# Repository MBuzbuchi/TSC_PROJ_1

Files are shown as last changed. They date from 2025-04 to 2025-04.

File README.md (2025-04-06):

# TSC_PROJ_1

E_Book proj

# _**Bloc Scheme**_


# _**Description of Hardware Functionality**_

Below is an extended list of the hardware components identified in the schematic, along with each component’s role and functionality, 
plus some operational details. These explanations help clarify how the entire system is built and why these design choices were made.

## 1. USB-C Connector & ESD Protection

### Key Components
- **USBLC6-2SC6Y** – TVS (Transient Voltage Suppressor) diode specialized for USB data line protection.  
  - **Approx. Price**: \$0.10–\$0.30 (single unit)  
- **PFMF.050.1** – resettable fuse (PTC) protecting the power line from excessive current.  
  - **Approx. Price**: \$0.10–\$0.20  
- **R2-USB1 / R2-USB** (5 kΩ) – matching/termination resistors on the USB D+ and D– data lines.  
  - **Approx. Price**: \$0.01–\$0.02 each  

### Function
- The USB-C connector supplies both power (5 V) to the system and USB data connectivity.  
- The ESD protection diode safeguards the USB data lines from electrostatic discharges up to several kV, maintaining the integrity of the data signals and internal converters.  
- The PTC fuse automatically resets once the current drops, preventing damage when short circuits or overcurrent situations occur on the USB port.

### Operational Data
- 5 V power supply from the USB, typically up to 500 mA (USB 2.0), or more depending on the USB-C source.  
- Data transfer rates up to 480 Mbps (USB 2.0 High Speed).

---

## 2. Voltage Regulators (LDO Voltage Regulator)

### Key Components
- **XC6220A331MR-G** – an LDO (Low Dropout) regulator delivering a stable 3.3 V output.  
  - **Approx. Price**: \$0.20–\$0.50  
- **DMG2305UX-7** – P-channel MOSFET used for power switching (possibly for reverse voltage protection or for reducing quiescent current when switching between USB and battery power).  
  - **Approx. Price**: \$0.10–\$0.30  

### Function
- Provides a constant 3.3 V rail for powering the ESP32-C6 and other logic circuits/sensors.  
- Can also serve as an additional protection stage, keeping the supply stable and filtering noise that may come from the USB source.

### Operational Data
- Input voltage range: ~3.5 V to 5.5 V (according to the LDO specs).  
- Output current up to ~300 mA.  
- Built-in overcurrent and thermal shutdown protection, ensuring circuit safety.

---

## 3. Li-Po Charging Controller (MCP73831/73832)

### Key Component
- **MCP73831** – a simple charge-management IC, configurable by an external resistor (PROG) to set the charge current.  
  - **Approx. Price**: \$0.50–\$0.80  

### Function
- Safely charges a single-cell Li-Po battery, regulating up to 4.2 V and controlling a maximum charge current.  
- Integrates temperature monitoring (via external NTC or dedicated resistor), charge status indicator (LED), and automatically switches to a float maintenance mode once the battery is fully charged.

### Operational Data
- Typically powered by a 5 V USB input.  
- Charge current (set by the PROG resistor) – e.g., 100 mA, 500 mA, etc., depending on the battery requirements.  
- Over-voltage, over-temperature, and short-circuit protection.

---

## 4. Single-Cell Li-Po Battery

### Function
- Stores electrical energy to power the device, enabling operation without a continuous USB supply.

### Operational Data
- Nominal voltage of ~3.7 V, fully charged at 4.2 V.  
- Capacity depends on the specific battery (500 mAh, 1000 mAh, etc.), which affects run time.  
- **Approx. Price**: Ranges from \$3 to \$8 or more, depending on capacity/brand.

---

## 5. ESP32-C6 Microcontroller (ESP32-C6-WROOM-1-N8)

### Function
- Core processing unit, running firmware and handling wireless communication (Wi-Fi 6, Bluetooth LE), as well as peripheral interfaces (SPI, I2C, UART, GPIO).  
- Integrates a 160 MHz RISC-V CPU, onboard Flash, SRAM, and hardware security features.

### Operational Data
- Powered at 3.3 V.  
- Low-power modes for efficient battery operation, ideal for portable IoT applications.  
- Interfaces with the E-Paper display (SPI), SD card (SPI), BME688 sensor (I2C), DS3231 RTC (I2C), and MAX17048 fuel gauge (I2C).  
- **Approx. Price**: \$2.50–\$5.00 (depending on memory size and supplier)

---

## 6. SD Card Interface

### Key Components
- MicroSD socket with card detection pins (CD, DETECTION_1, DETECTION_2).  
  - **Approx. Price**: \$0.40–\$1.00

### Function
- Provides a removable storage option for logging data, configuration files, E-Paper images, etc.  
- Uses SPI lines (SCK, MISO, MOSI, SS_SD) for communication with the ESP32-C6.

### Operational Data
- Operates at 3.3 V.  
- Supports SD/SDHC cards up to multiple GB, depending on firmware support.
- SD card itself (not included in the socket cost) can range from \$3 to \$20+ depending on capacity and speed class.

---

## 7. E-Paper Drive Circuit

### Key Components
- **MBR0530** Schottky diodes (e.g., D3, D4, D5) for protection and rectification in the voltage-boosting section.  
  - **Approx. Price**: \$0.05–\$0.10 each  
- **Inductor L1** (68 µH) for boost converter operation.  
  - **Approx. Price**: \$0.10–\$0.30 (depends on current rating)  
- **SI1308EDL-T1-GE3** MOSFET for switching in the high-voltage generator.  
  - **Approx. Price**: \$0.15–\$0.30  

### Function
- Creates the specialized positive and negative voltages (EPD_VGH, EPD_VGL) required by the E-Paper display.  
- Converts 3.3 V into higher and/or negative voltages needed to update the E-Ink display.

### Operational Data
- Typical output ranges: +15…22 V and -15…22 V (depending on the specific panel).  
- MBR0530 diodes have a low forward drop and can handle relatively high currents for this type of circuit.

---

## 8. Display Type Selector

### Key Components
- Jumper **SJ1**, resistor **R2** (2.2 kΩ).  
  - **Approx. Price**: Jumper \$0.05–\$0.10, resistor \$0.01–\$0.02

### Function
- Allows configuration of control pins (e.g. **RES**, **BUSY**) or power lines to support various E-Paper panel types.  
- Moving the jumper can route or enable certain lines depending on the display’s requirements.

---

## 9. E-Paper Display Header

### Component
- FFC (Flat Flex Cable) connector, **FH34SRJ-24S-0.5SH** (24-pin) or similar.  
  - **Approx. Price**: \$0.40–\$0.80

### Function
- A mechanical and electrical interface between the main board and the E-Paper module.  
- Includes SPI signals (SCK, MOSI, MISO—if bi-directional), control signals (CS, DC), reset line (RES), busy line (BUSY), and power lines (3.3 V, GND, EPD_VGH, EPD_VGL).

---

## 10. Battery Fuel Gauge (MAX17048)

### Key Component
- **MAX17048G+T10** – Fuel gauge with an I²C interface.  
  - **Approx. Price**: \$1.20–\$2.00

### Function
- Measures the Li-Po battery voltage and estimates its state of charge (SOC) in real time, compensating for temperature and discharge characteristics.  
- Allows the microcontroller to display battery level and react to critical low-battery states.

### Operational Data
- I²C interface at 3.3 V.  
- ±1–2% SOC accuracy.  
- Configurable alert output for low battery.

---

## 11. External Flash Memory (W25Q512JVEIQ, 64MB)

### Function
- Additional non-volatile storage (up to 64Mb or 512Mbit, i.e. 8 MB, depending on suffix) for images, fonts, configuration files, and Over-the-Air (OTA) firmware updates.

### Operational Data
- SPI interface with speeds up to 133 MHz.  
- 3.3 V supply voltage.  
- Up to 100,000 write/erase cycles and 20-year data retention.  
- **Approx. Price**: \$1.50–\$3.00 (depending on density and supplier)

---

## 12. SPI ESD Protection Lines

### Key Components
- **PGB1010603MR** (Polymeric ESD Suppressor) and 10 kΩ series resistors.  
  - **Approx. Price**: \$0.05–\$0.15 each for the suppressors, \$0.01 for each resistor

### Function
- Protects SPI data lines from electrostatic discharges, which can occur when plugging in peripherals or when the lines are touched without proper handling.  
- The 10 kΩ resistors help limit transient current before it reaches the TVS diode, providing additional filtering.

### Operational Data
- ESD protection up to ±8 kV (contact discharge).

---

## 13. Qwiic / Stemma QT Connector (I2C)

### Component
- 4-pin connector (GND, 3.3 V, SDA, SCL).  
  - **Approx. Price**: \$0.30–\$0.60

### Function
- Provides a standardized, plug-and-play interface for quickly adding I2C-based sensors or other modules.

### Operational Data
- Compatible with SparkFun Qwiic and Adafruit Stemma QT systems.  
- 3.3 V supply voltage.

---

## 14. RTC Module (DS3231SN)

### Key Component
- **DS3231SN** – A high-accuracy real-time clock with an integrated temperature-compensated oscillator (TCXO).  
  - **Approx. Price**: \$1.50–\$3.00

### Function
- Maintains precise timekeeping with minimal drift (±2 ppm, equivalent to ±1 minute/year in some conditions).  
- Communicates with the microcontroller via I²C for automatic time syncing.  
- Can keep time even when main power is off, using a backup battery on VBAT.

### Operational Data
- 3.3 V supply voltage.  
- Operating temperature range from -40 °C to +85 °C (depending on the specific version).

---

## 15. Test Pads

### Component
- Test points (TP1…TP17) placed around the PCB.  
  - **Approx. Price**: Usually negligible (just copper pads), sometimes \$0.01–\$0.02 each if you count plating cost.

### Function
- Provide direct access to key signals (SPI, I2C, GPIO) for debugging, measurements, programming, or firmware updates.  
- Highly useful for prototyping, quality control, and mass production validation.

---

# _**Bill of Materials**_
Data sheets and links to websites were included only at the first mention of components that appear multiple times in the project. Components such as test points (TP), do not have tehnical description or present a data sheet because these were designed personally

| Name of component  | Device | Check Prices | DataSheet |
|---|---|---|---|
| BOOT_BUTTON | BUTTON_CUSYOMV1 | [Check Price](https://industry.panasonic.com/global/en/products/control/switch/light-touch/number/evqpuj02k)  | [DataSheet](https://industry.panasonic.com/global/en/products/control/switch/light-touch/number/evqpuj02k) |
| C1 | ESP32_WROVER_EAGLE-LTSPICE_CC0402 | [Check Price](https://industry.panasonic.com/global/en/products/control/switch/light-touch/number/evqpuj02k)  | [DataSheet](https://industry.panasonic.com/global/en/products/control/switch/light-touch/number/evqpuj02k) |
| C1_BAT | ESP32_WROVER_EAGLE-LTSPICE_CC0402 | #N/A | #N/A |
| C1_BAT1 | EAGLE-LTSPICE_CC0402 | #N/A | #N/A |
| C1_BAT2 | EAGLE-LTSPICE_CC0402 | #N/A | #N/A |
| C2 | ESP32_WROVER_EAGLE-LTSPICE_CC0402 | #N/A | #N/A |
| C2_BAT\ | ESP32_WROVER_EAGLE-LTSPICE_CC0402 | #N/A | #N/A |
| C3 | RCL_CPOL-EUCT3528 | #N/A | #N/A |
| C4 | ESP32_WROVER_EAGLE-LTSPICE_CC0402 | #N/A | #N/A |
| C4_USB | ESP32_WROVER_EAGLE-LTSPICE_CC0402 | #N/A | #N/A |
| C5 | ESP32_WROVER_EAGLE-LTSPICE_CC0402 | #N/A | #N/A |
| C5_USB | ESP32_WROVER_EAGLE-LTSPICE_CC0402 | #N/A | #N/A |
| C6 | ESP32_WROVER_EAGLE-LTSPICE_CC0402 | #N/A | #N/A |
| C7 | ESP32_WROVER_EAGLE-LTSPICE_CC0402 | #N/A | #N/A |
| C8 | ESP32_WROVER_EAGLE-LTSPICE_CC0402 | #N/A | #N/A |
| C9 | EAGLE-LTSPICE_CC0402 | #N/A | #N/A |
| C10 | ESP32_WROVER_EAGLE-LTSPICE_CC0402 | #N/A | #N/A |
| C10_SUPERCAP | CPH3225A | [Check Price](https://www.snapeda.com/parts/CPH3225A/Seiko+Instruments/view-part/?ref=eda) | [DataSheet](https://www.snapeda.com/parts/CPH3225A/Seiko+Instruments/view-part/?ref=eda) |
| CHANGE_BUTTON | BUTTON_CUSYOMV1 | [Check Price](https://industry.panasonic.com/global/en/products/control/switch-light-touch/number/evqpuj02k)  | [DataSheet](https://industry.panasonic.com/global/en/products/control/switch-light-touch/number/evqpuj02k) |
| CHG_LED | ADAFRUIT_LEDCHIP-LED0603 | [Check Price](https://www.snapeda.com/parts/KP-1608SURCK/Kingbright/view-part/?ref=search&t=LED%200603) | [DataSheet](https://www.snapeda.com/parts/KP-1608SURCK/Kingbright/view-part/?ref=search&t=LED%200603) |
| C_DELAY | ESP32_WROVER_EAGLE-LTSPICE_CC0402 | #N/A | #N/A |
| D1 | USBLC6-2SC6Y | [Check Price](https://www.snapeda.com/parts/USBLC6-2SC6Y/STMicroelectronics/view-part/?ref=eda) | [DataSheet](https://www.snapeda.com/parts/USBLC6-2SC6Y/STMicroelectronics/view-part/?ref=eda) |
| D2 | ESP32_WROVER_AVX---SD0805S020S1R0_AVX_... | [Check Price](https://eu.mouser.com/ProductDetail/KYOCERA-AVX/SD0805S020S1R0?qs=jCA%252BPfw4LHbpkAoSnwrdjw%3D%3D) | [DataSheet](http://datasheets.avx.com/schottky.pdf) |
| D3 | MBR0530 | [Check Price](https://eu.mouser.com/ProductDetail/KYOCERA-AVX/SD0805S020S1R0?qs=jCA%252BPfw4LHbpkAoSnwrdjw%3D%3D) | [DataSheet](https://eu.mouser.com/ProductDetail/KYOCERA-AVX/SD0805S020S1R0?qs=jCA%252BPfw4LHbpkAoSnwrdjw%3D%3D) |
| D4 | MBR0530 | [Check Price](https://www.snapeda.com/parts/MBR0530/Onsemi/view-part/?ref=eda) | [DataSheet](https://www.snapeda.com/parts/MBR0530/Onsemi/view-part/?ref=eda) |
| D5 | MBR0530 | [Check Price](https://www.snapeda.com/parts/MBR0530/Onsemi/view-part/?ref=eda) | [DataSheet](https://www.snapeda.com/parts/MBR0530/Onsemi/view-part/?ref=eda) |
| D6 | PGB1010603MR | [Check Price](https://www.snapeda.com/parts/PGB1010603MR/Littelfuse/view-part/?ref=eda) | [DataSheet](https://www.snapeda.com/parts/PGB1010603MR/Littelfuse/view-part/?ref=eda) |
| D7 | ESP32_WROVER_AVX---SD0805S020S1R0_AVX_... | [Check Price](https://eu.mouser.com/ProductDetail/KYOCERA-AVX/SD0805S020S1R0?qs=jCA%252BPfw4LHbpkAoSnwrdjw%3D%3D) | [DataSheet](http://datasheets.avx.com/schottky.pdf) |
| D8 | PGB1010603MR | [Check Price](https://www.snapeda.com/parts/PGB1010603MR/Littelfuse/view-part/?ref=eda) | [DataSheet](https://www.snapeda.com/parts/PGB1010603MR/Littelfuse/view-part/?ref=eda) |
| D9 | PGB1010603MR | [Check Price](https://www.snapeda.com/parts/PGB1010603MR/Littelfuse/view-part/?ref=eda) | [DataSheet](https://www.snapeda.com/parts/PGB1010603MR/Littelfuse/view-part/?ref=eda) |
| D10 | PGB1010603MR | [Check Price](https://www.snapeda.com/parts/PGB1010603MR/Littelfuse/view-part/?ref=eda) | [DataSheet](https://www.snapeda.com/parts/PGB1010603MR/Littelfuse/view-part/?ref=eda) |
| D11 | PGB1010603MR | [Check Price](https://www.snapeda.com/parts/PGB1010603MR/Littelfuse/view-part/?ref=eda) | [DataSheet](https://www.snapeda.com/parts/PGB1010603MR/Littelfuse/view-part/?ref=eda) |
| D12 | PGB1010603MR | [Check Price](https://www.snapeda.com/parts/PGB1010603MR/Littelfuse/view-part/?ref=eda) | [DataSheet](https://www.snapeda.com/parts/PGB1010603MR/Littelfuse/view-part/?ref=eda) |
| EPD_C1 | ESP32_WROVER_EAGLE-LTSPICE_CC0402 | #N/A | #N/A |
| EPD_C2 | ESP32_WROVER_EAGLE-LTSPICE_CC0402 | #N/A | #N/A |
| EPD_C5 | ESP32_WROVER_EAGLE-LTSPICE_CC0402 | #N/A | #N/A |
| EPD_C6 | ESP32_WROVER_EAGLE-LTSPICE_CC0402 | #N/A | #N/A |
| EPD_C7 | ESP32_WROVER_EAGLE-LTSPICE_CC0402 | #N/A | #N/A |
| EPD_C8 | ESP32_WROVER_EAGLE-LTSPICE_CC0402 | #N/A | #N/A |
| EPD_C9 | ESP32_WROVER_EAGLE-LTSPICE_CC0402 | #N/A | #N/A |
| EPD_C10 | ESP32_WROVER_EAGLE-LTSPICE_CC0402 | #N/A | #N/A |
| EPD_C11 | ESP32_WROVER_EAGLE-LTSPICE_CC0402 | #N/A | #N/A |
| EPD_C12 | ESP32_WROVER_EAGLE-LTSPICE_CC0402 | #N/A | #N/A |
| IC1 | BD5229G-TR | [Check Price](https://componentsearchengine.com/part-view/BD5229G-TR/ROHM%20Semiconductor) | [DataSheet](https://componentsearchengine.com/part-view/BD5229G-TR/ROHM%20Semiconductor) |
| IC4 | XC6220A331MR-G | [Check Price](https://componentsearchengine.com/part-view/XC6220A331MR-G/Torex) | [DataSheet](https://componentsearchengine.com/part-view/XC6220A331MR-G/Torex) |
| J1 | FH34SRJ-24S-0.5SH_99_ | [Check Price](https://componentsearchengine.com/part-view/XC6220A331MR-G/Torex) | [DataSheet](https://componentsearchengine.com/part-view/XC6220A331MR-G/Torex) |
| J2 | SAMACSYS_PARTS_USB4110-GF-A | [Check Price](https://componentsearchengine.com/part-view/USB4110-GF-A/GCT%20(GLOBAL%20CONNECTOR%20TECHNOLOGY) | [DataSheet](https://componentsearchengine.com/part-view/USB4110-GF-A/GCT%20(GLOBAL%20CONNECTOR%20TECHNOLOGY) |
| J3 | QWIIC_CONNECTORJS-1MM | #N/A | #N/A |
| J4 | 112A-TAAR-R03_ATTEND | [Check Price](https://store.comet.srl.ro/Catalogue/Product/43497/) | [DataSheet](https://store.comet.srl.ro/Catalogue/Product/43497/) |
| L1 | 744043680IND_4828-WE-TPC_WRE | [Check Price](https://eu.mouser.com/ProductDetail/Wurth-Elektronik/744043680?qs=PGXP4M47uW6VkZq%252BkzjrHA%3D%3D) | [DataSheet](https://eu.mouser.com/ProductDetail/Wurth-Elektronik/744043680?qs=PGXP4M47uW6VkZq%252BkzjrHA%3D%3D) |
| PFMF.050.1 | ESP32C6_VARISTORCN1812 | [Check Price](https://www.mouser.co.uk/ProductDetail/EPCOS-TDK/B72520T0350K062?qs=dEfas%2FXlABIszF52uu7vrg%3D%3D) | [DataSheet](https://www.mouser.co.uk/ProductDetail/EPCOS-TDK/B72520T0350K062?qs=dEfas%2FXlABIszF52uu7vrg%3D%3D) |
| Q1 | ESP32_WROVER_SPARKFUN-DISCRETESEMI_MOSFET_... | [Check Price](https://componentsearchengine.com/part-view/DMG2305UX-7/Diodes%20Incorporated) | [DataSheet](https://componentsearchengine.com/part-view/DMG2305UX-7/Diodes%20Incorporated) |
| Q2 | ESP32_WROVER_SPARKFUN-DISCRETESEMI_MOSFET_... | #N/A | #N/A |
| Q3 | D8 | [Check Price](https://componentsearchengine.com/part-view/PGB1010603MR/Littelfuse) | [DataSheet](https://componentsearchengine.com/part-view/PGB1010603MR/Littelfuse) |
| Q4 | Q2_TS-B2_REACHPACK | #N/A | #N/A |

# _**Pin Allocation for ESP32-C6**_

| Pin ESP32-C6  | Componentă / Semnal | Explicație |
|---|---|---|
| GPIO1 | I²C SDA (BME688, MAX17048, DS3231, Qwiic) | Se folosește pentru a partaja magistrala I²C între toți senzorii și RTC. |
| GPIO2 | I²C SCL (BME688, MAX17048, DS3231, Qwiic) | Linia de clock pentru comunicarea I²C. |
| GPIO5 | SPI MISO (E-Paper) | Pinul pentru citirea datelor sau a statusului de la ecranul e-paper. |
| GPIO6 | SPI MOSI (E-Paper) | Trimiterea datelor către ecranul e-paper. |
| GPIO7 | SPI CLK (E-Paper) | Semnal de clock pentru sincronizarea cu e-paper. |
| GPIO8 | SPI CS (E-Paper) | Chip Select pentru a activa comunicarea cu e-paper.  |
| GPIO9 | E-Paper DC (Data/Command) | Semnal pentru a diferenția între date și comenzi pentru ecranul e-paper. |
| GPIO10 | E-Paper RST | Pinul de reset hardware pentru e-paper. |
| GPIO11 | E-Paper BUSY | Intrare din display care indică dacă ecranul este ocupat sau nu. |
| GPIO12 | Button #1 | Intrare digitală pentru primul buton (ex. pagina următoare). |
| GPIO13 | Button #2 | Intrare digitală pentru al doilea buton (ex. pagina anterioară). |
| GPIO14 | Button #3 | Intrare digitală pentru al treilea buton (ex. Meniu/OK). |
| GPIO15 | MAX17048 ALERT (opțional) | Semnal de alertă de la MAX17048 pentru nivel scăzut al bateriei. |
| GPIO16 | USB D+ (intern la USB PHY) | Pin dedicat pentru semnalul USB 2.0 (D+). |
| GPIO17 | USB D- (intern la USB PHY) | Pin dedicat pentru semnalul USB 2.0 (D-). |
| GPIO18 | LED de status (opțional) | Indicator pentru diverse stări (ex. Wi-Fi, încărcare, etc.). |
| GPIO19 | SD Card CS (opțional) | Chip Select pentru cardul SD (dacă se folosește SPI). |
| GPIO20 | SD Card MISO (opțional) | Intrare date de la cardul SD. |
| GPIO21 | SD Card MOSI (opțional) | Ieșire date către cardul SD. |
| GPIO4 | SD Card CLK (opțional) | Semnal de clock pentru cardul SD (SPI). |

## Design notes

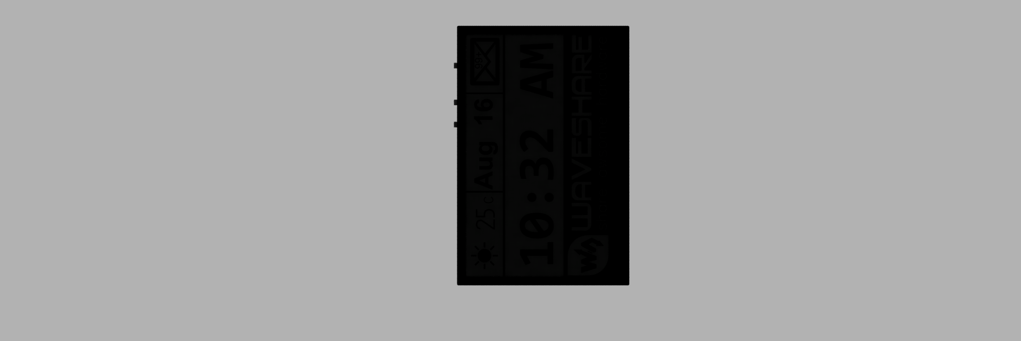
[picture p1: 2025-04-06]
images/OpenBook_Enclosure_2025-Apr-06_09-25-51PM-000_CustomizedView29206264894.png

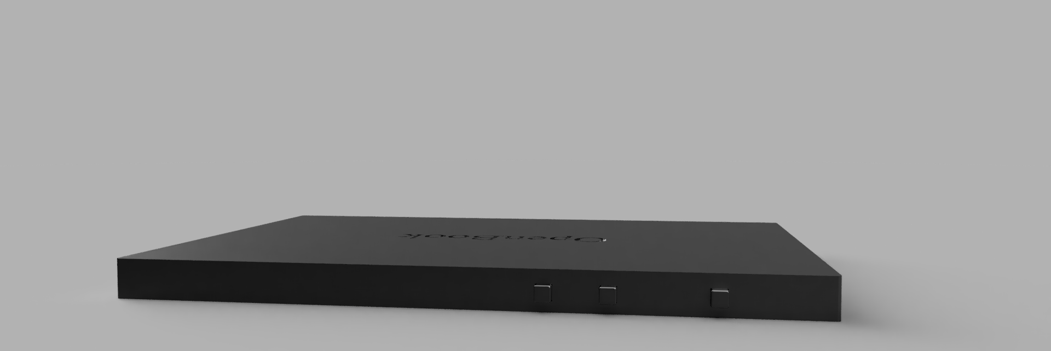
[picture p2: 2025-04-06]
images/OpenBook_Enclosure_2025-Apr-06_09-26-25PM-000_CustomizedView46279044438.png

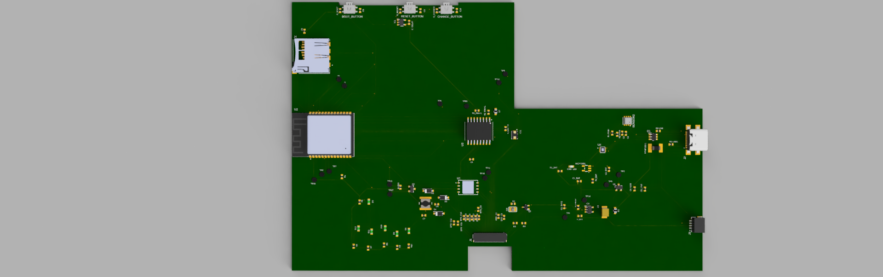
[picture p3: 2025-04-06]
images/PCB_E_BOOK_v1_2025-Apr-06_09-19-09PM-000_CustomizedView10956669207.png

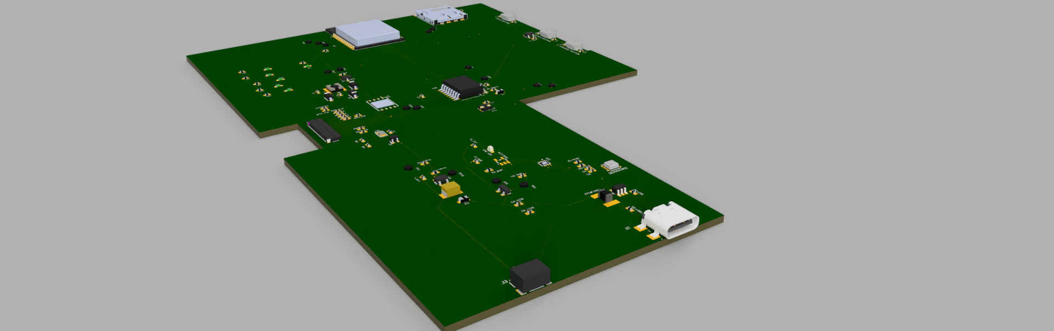
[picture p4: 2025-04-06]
images/PCB_E_BOOK_v1_2025-Apr-06_09-20-42PM-000_CustomizedView36226968305.png

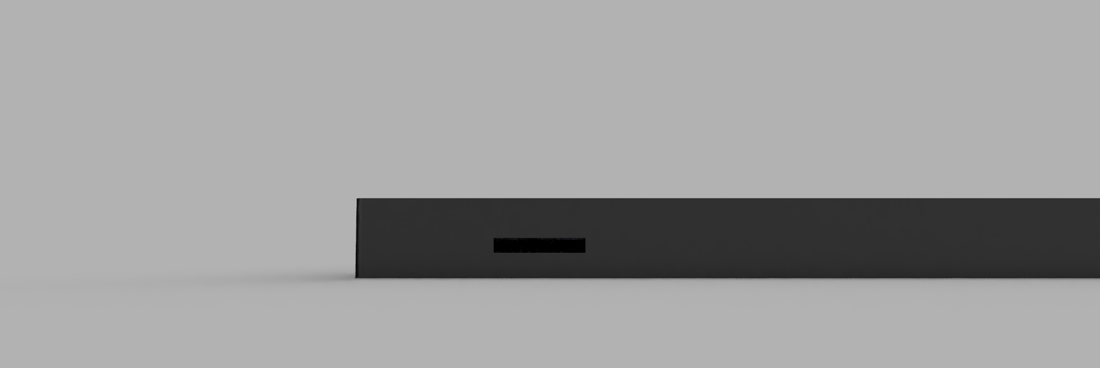
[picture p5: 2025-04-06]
images/OpenBook_Enclosure_2025-Apr-06_09-29-12PM-000_CustomizedView25638107718.png

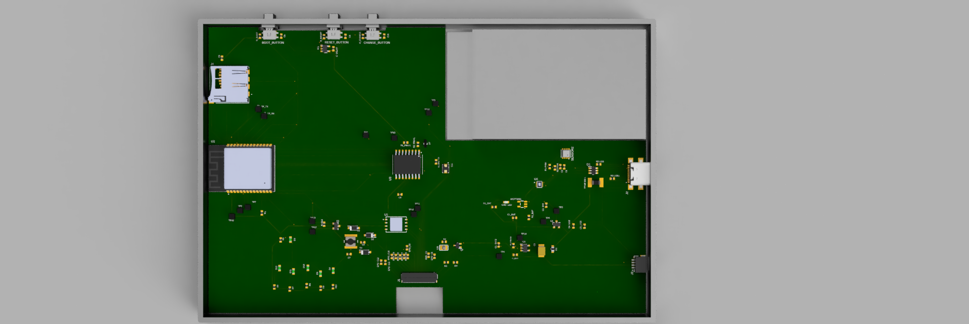
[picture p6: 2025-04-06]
images/OpenBook_Enclosure_2025-Apr-06_09-32-38PM-000_CustomizedView49546291209.png

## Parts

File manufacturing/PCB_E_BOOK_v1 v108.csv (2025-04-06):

Qty | Value | Device | Package | Parts | Description | ARROW_PART_NUMBER | ARROW_PRICE-STOCK | AVAILABILITY | CHECK_PRICES | DESCRIPTION | HEIGHT | MANUFACTURER_NAME | MANUFACTURER_PART_NUMBER | MF | MOUSER_PART_NUMBER | MOUSER_PRICE-STOCK | MOUSER_TESTING_PART_NUMBER | MOUSER_TESTING_PRICE-STOCK | MP | PACKAGE | POPULARITY | PRICE | PROD_ID | PURCHASE-URL | SNAPEDA_LINK | SPICEPREFIX | VALUE
1 |  | ADAFRUIT_LEDCHIP-LED0603 | ADAFRUIT_CHIP-LED0603 | CHG_LED | LED
1 |  | SJ | SJ | SJ1 | SMD solder JUMPER |  |  |  |  |  |  |  |  |  |  |  |  |  |  |  | 3
1 | 0.47 | ESP32_WROVER_EAGLE-LTSPICE_RR0402 | ESP32_WROVER_EAGLE-LTSPICE_R0402 | R3 | RESISTOR, European symbol
1 | 100K | ESP32_WROVER_EAGLE-LTSPICE_RR0402 | ESP32_WROVER_EAGLE-LTSPICE_R0402 | R1_PWRUSB | RESISTOR, European symbol
8 | 100nF | EAGLE-LTSPICE_C | EAGLE-LTSPICE_C0402 | C1, C2, C4_USB, C6, C8, C9, C10, C_DELAY | CAPACITOR, European symbol
1 | 100uF TANT | RCL_CPOL-EUCT3528 | RCL_CT3528 | C3 | POLARIZED CAPACITOR, European symbol |  |  |  |  |  |  |  |  |  |  |  |  |  |  |  | 0 |  |  |  |  | C
14 | 10K | ESP32_WROVER_EAGLE-LTSPICE_RR0402 | ESP32_WROVER_EAGLE-LTSPICE_R0402 | R1, R1-PINH, R1_PINH1, R2-PINH, R2_PINH1, R5, R6, R7, R8, R9, R10, R_BOOT, R_CL1, R_RESET | RESISTOR, European symbol
2 | 10k | ESP32_WROVER_EAGLE-LTSPICE_RR0402 | ESP32_WROVER_EAGLE-LTSPICE_R0402 | R4, R_CHANGE | RESISTOR, European symbol
2 | 10uF | EAGLE-LTSPICE_C | EAGLE-LTSPICE_C0402 | C1_BAT, C7 | CAPACITOR, European symbol
1 | 112A-TAAR-R03_ATTEND | 112A-TAAR-R03_ATTEND | 112ATAARR03ATTEND | J4 | Micro SD Card Socket, Push-Push Type, Top Mount, SMT, H=1.83mm, 10u |  |  |  |  | Micro SD Card Socket | Push-Push Type | Top Mount | SMT | H=1.83mm | 10u | 1.9mm | ATTEND | 112A-TAAR-R03 ATTEND
1 | 15 | ESP32_WROVER_EAGLE-LTSPICE_RR0402 | ESP32_WROVER_EAGLE-LTSPICE_R0402 | R_CAPACITOR | RESISTOR, European symbol
1 | 1uF | EAGLE-LTSPICE_C | EAGLE-LTSPICE_C0402 | C5 | CAPACITOR, European symbol
10 | 1uF/50v | EAGLE-LTSPICE_C | EAGLE-LTSPICE_C0402 | EPD_C1, EPD_C2, EPD_C5, EPD_C6, EPD_C7, EPD_C8, EPD_C9, EPD_C10, EPD_C11, EPD_C12 | CAPACITOR, European symbol
1 | 2.2 | ESP32_WROVER_EAGLE-LTSPICE_RR0402 | ESP32_WROVER_EAGLE-LTSPICE_R0402 | R2 | RESISTOR, European symbol
1 | 200 | ESP32_WROVER_EAGLE-LTSPICE_RR0402 | ESP32_WROVER_EAGLE-LTSPICE_R0402 | R1_BAT | RESISTOR, European symbol
2 | 20V/4.2A/52mO/1.4W | ESP32_WROVER_SPARKFUN-DISCRETESEMI_MOSFET_PCH-DMG2305UX-7 | ESP32_WROVER_SPARKFUN-DISCRETESEMI_SOT23-3 | Q1, Q2 | P-channel MOSFETs |  |  |  |  |  |  |  |  |  |  |  |  |  |  |  |  |  | TRAN-14388 |  |  |  | 20V/4.2A/52mO/1.4W
1 | 2K | ESP32_WROVER_EAGLE-LTSPICE_RR0402 | ESP32_WROVER_EAGLE-LTSPICE_R0402 | R2_BAT | RESISTOR, European symbol
4 | 4.7uF | EAGLE-LTSPICE_C | EAGLE-LTSPICE_C0402 | C1_BAT1, C1_BAT2, C2_BAT, C5_USB | CAPACITOR, European symbol
1 | 4.7uF/25V | EAGLE-LTSPICE_C | EAGLE-LTSPICE_C0402 | C4 | CAPACITOR, European symbol
2 | 5k1 | ESP32_WROVER_EAGLE-LTSPICE_RR0402 | ESP32_WROVER_EAGLE-LTSPICE_R0402 | R2-USB, R2-USB1 | RESISTOR, European symbol
1 | 68uH | 744043680 | IND_4828-WE-TPC_WRE | L1
1 | BD5229G-TR | BD5229G-TR | SOT95P280X125-5N | IC1 | Voltage Detector with Adjustable Delay Time: CMOS processes are utilized to develop high precision, low current consumption CMOS reset ICs that allow arbitrary setting of the delay time. The extensive lineup includes both Nch Open Drain and CMOS output types in a wide range of detection voltages (from 2.3V to 6.0V, in 0.1V steps), enabling selection of the ideal solution based on customer requirements. In addition, the entire series is of course both lead-free and RoHS-compliant. |  |  |  |  | Voltage Detector with Adjustable Delay Time: CMOS processes are utilized to develop high precision | low current consumption CMOS reset ICs that allow arbitrary setting of the delay time. The extensive lineup includes both Nch Open Drain and CMOS output types in a wide range of detection voltages (from 2.3V to 6.0V | in 0.1V steps) | enabling selection of the ideal solution based on customer requirements. In addition | the entire series is of course both lead-free and RoHS-compliant. | 1.25mm | ROHM Semiconductor | BD5229G-TR |  | 755-BD5229G-TR | https://www.mouser.co.uk/ProductDetail/ROHM-Semiconductor/BD5229G-TR?qs=4kLU8WoGk0vvnhrrYwdszw%3D%3D
3 | BUTTON_CUSYOMV1 | BUTTON_CUSYOMV1 | MYBUTTON | BOOT_BUTTON, CHANGE_BUTTON, RESET_BUTTON
1 | CPH3225A | CPH3225ACPH3225A_3D | CAPCP3225X100N | C11 | Cap 0.011F 3.3V 1210 Flat Check availability
1 | DS3231SN# | DS3231SN# | SOIC127P1032X265-16N | U3 | Real Time Clock Serial 16-Pin SOIC W T/R Check availability |  |  | In Stock | https://www.snapeda.com/parts/DS3231SN%23/Analog+Devices/view-part/?ref=eda | Extremely Accurate I²C-Integrated RTC/TCXO/Crystal |  |  |  | Analog Devices |  |  |  |  | DS3231SN# | SOIC-16 Maxim |  | None |  | https://www.snapeda.com/api/url_track_click_mouser/?unipart_id=99048&manufacturer=Analog Devices&part_name=DS3231SN#&search_term=None | https://www.snapeda.com/parts/DS3231SN%23/Analog+Devices/view-part/?ref=snap
1 | ESP32-C6-WROOM-1-N8 | ESP32-C6-WROOM-1-N8 | XCVR_ESP32-C6-WROOM-1-N8 | U2 | Check availability |  |  | In Stock | https://www.snapeda.com/parts/ESP32-C6-WROOM-1-N8/Espressif+Systems/view-part/?ref=eda | Multiprotocol Modules ESP32-C6 module | Wi-Fi 6 in 2.4 GHz band | Bluetooth 5 | Zigbee 3.0 and Thread. ESP34-WROOM Compatible - ENGINEERING SAMPLE |  |  |  | Espressif Systems |  |  |  |  | ESP32-C6-WROOM-1-N8 | None |  | None
1 | ESP32C6_VARISTORCN1812 | ESP32C6_VARISTORCN1812 | ESP32C6_VARISTOR_CT/CN1812 | PFMF.050.1 | VARISTOR |  |  |  |  |  |  |  |  |  |  |  |  |  |  |  | 0
1 | ESP32_WROVER_AVX---SD0805S020S1R0_AVX_SD0805S020S1R0_0_0 | ESP32_WROVER_AVX---SD0805S020S1R0_AVX_SD0805S020S1R0_0_0 | ESP32_WROVER_AVX---SD0805S020S1R0_AVX_SD0805S020S1R0_0 | D7 | Schottky Barrier Rectifier Diode
1 | ESP32_WROVER_BME680_BME680 | ESP32_WROVER_BME680_BME680 | ESP32_WROVER_BME680_PSON80P300X300X100-8N | SENSOR2 | Integrated Environmental Unit |  |  | Unavailable |  | Integrated Environmental Unit |  |  |  | Bosch Sensortec |  |  |  |  | BME680 | LGA-8 Bosch Tools |  | None
1 | ESP32_WROVER_SPARKFUN-IC-POWER_MCP73831 | ESP32_WROVER_SPARKFUN-IC-POWER_MCP73831 | ESP32_WROVER_SPARKFUN-IC-POWER_SOT23-5 | MCP73831 | MCP73831T Li-Ion, Li-Pol Controller |  |  |  |  |  |  |  |  |  |  |  |  |  |  |  |  |  | IC-09995
1 | FH34SRJ-24S-0.5SH_99_ | FH34SRJ-24S-0.5SH_99_ | FH34SRJ24S05SH99 | J1 | (0.50mm) Surface Mount, Right Angle |  |  |  |  | 24 Position FFC | FPC Connector Contacts | (0.50mm) Surface Mount | Right Angle | 1.1mm | Hirose | FH34SRJ-24S-0.5SH(99) |  | 798-FH34SRJ24S05SH99 | https://www.mouser.co.uk/ProductDetail/Hirose-Connector/FH34SRJ-24S-0.5SH99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
1 | MAX17048G+T10 | MAX17048G+T10 | SON50P200X200X80-9N | U4 | Check availability |  |  | In Stock | https://www.snapeda.com/parts/MAX17048G+T10/Analog+Devices/view-part/?ref=eda | 3µA 1-Cell/2-Cell Fuel Gauge with ModelGauge |  |  |  | Analog Devices |  |  |  |  | MAX17048G+T10 | TDFN-8 Maxim |  | None |  | https://www.snapeda.com/api/url_track_click_mouser/?unipart_id=329239&manufacturer=Analog Devices&part_name=MAX17048G+T10&search_term=None | https://www.snapeda.com/parts/MAX17048G+T10/Analog+Devices/view-part/?ref=snap
3 | MBR0530 | MBR0530 | SOD3716X135N | D3, D4, D5 | ON SEMICONDUCTOR - MBR0530 - DIODE, SCHOTTKY, 0.5A, 30V, SOD-123
6 | PGB1010603MR | PGB1010603MRPGB1010603MR2 | DIOC1608X36N | D6, D8, D9, D10, D11, D12 | Check availability
1 | QWIIC_RIGHT_ANGLE | QWIIC_CONNECTORJS-1MM | JST04_1MM_RA | J3 | SparkFun I2C Standard Qwiic Connector |  |  |  |  |  |  |  |  |  |  |  |  |  |  |  |  |  | CONN-13694 |  |  |  | QWIIC_RIGHT_ANGLE
1 | SAMACSYS_PARTS_USB4110-GF-A | SAMACSYS_PARTS_USB4110-GF-A | SAMACSYS_PARTS_USB4110GFA | J2 | CONN USB 2.0 TYPE-C R/A SMT |  |  |  |  | CONN USB 2.0 TYPE-C R/A SMT | 3.26mm | GCT (GLOBAL CONNECTOR TECHNOLOGY) | USB4110-GF-A |  | 640-USB4110-GF-A | https://www.mouser.co.uk/ProductDetail/GCT/USB4110-GF-A?qs=KUoIvG%2F9IlYiZvIXQjyJeA%3D%3D
1 | SD0805S020S1R0 | ESP32_WROVER_AVX---SD0805S020S1R0_AVX_SD0805S020S1R0_0_0 | ESP32_WROVER_AVX---SD0805S020S1R0_AVX_SD0805S020S1R0_0 | D2 | Schottky Barrier Rectifier Diode
1 | SI1308EDL-T1-GE3 | SI1308EDL-T1-GE3 | SOT65P210X110-3N | Q3 | MOSFET N-Ch 30V 1.5A TrenchFET SC70 Vishay Si1308EDL-T1-GE3 N-channel MOSFET Transistor, 1.5 A, 30 V, 3-Pin SC-70 |  |  | In Stock | https://www.snapeda.com/parts/SI1308EDL-T1-GE3/Vishay+Siliconix/view-part/?ref=eda | Si1308EDL-T1-GE3 N-channel MOSFET Transistor | 1.5 A | 30 V | 3-Pin SC-70 | Siliconix / Vishay SI1308EDL-T1-GE3 |  |  |  | Vishay Siliconix |  |  |  |  | SI1308EDL-T1-GE3 | SOT-323 Vishay Semiconductor |  | None |  | https://www.snapeda.com/api/url_track_click_mouser/?unipart_id=274603&manufacturer=Vishay Siliconix&part_name=SI1308EDL-T1-GE3&search_term=None
17 | TPTP20R | TPTP20R | TP20R | TP1, TP2, TP3, TP4, TP5, TP6, TP7, TP8, TP9, TP10, TP11, TP12, TP13, TP14, TP15, TP16, TP17 | Test pad
1 | USBLC6-2SC6Y | USBLC6-2SC6Y | SOT95P280X145-6N | D1 | Low Cap. ESD Protection Auto SOT-23-6 STMicroelectronics USBLC6-2SC6Y, Dual Uni-Directional TVS Diode Array, 6-Pin SOT-23 |  |  | In Stock | https://www.snapeda.com/parts/USBLC6-2SC6Y/STMicroelectronics/view-part/?ref=eda | 17V Clamp 5A (8/20µs) Ipp Tvs Diode Surface Mount SOT-23-6 |  |  |  | STMicroelectronics |  |  |  |  | USBLC6-2SC6Y | SOT-23-6 STMicroelectronics |  | None |  |  | https://www.snapeda.com/parts/USBLC6-2SC6Y/STMicroelectronics/view-part/?ref=snap
1 | W25Q512JVEIQ | W25Q512JVEIQ | SON127P600X800X80-9N | U1 | Check availability |  |  | In Stock | https://www.snapeda.com/parts/W25Q512JVEIQ/Winbond+Electronics/view-part/?ref=eda | FLASH - NOR Memory IC 512Mb (64M x 8) SPI - Quad I/O 133 MHz 8-WSON (8x6) |  |  |  | Winbond Electronics |  |  |  |  | W25Q512JVEIQ | Package |  | None |  |  | https://www.snapeda.com/parts/W25Q512JVEIQ/Winbond+Electronics/view-part/?ref=snap
1 | XC6220A331MR-G | XC6220A331MR-G | SOT95P280X120-5N | IC4 | LDO Voltage Regulators |  |  |  |  | LDO Voltage Regulators | 1.2mm | Torex | XC6220A331MR-G |  | 865-XC6220A331MR-G | https://www.mouser.co.uk/ProductDetail/Torex-Semiconductor/XC6220A331MR-G?qs=AsjdqWjXhJ8ZSWznL1J0gg%3D%3D

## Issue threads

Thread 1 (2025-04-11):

PCB Issues

CosminCroitoriu, 2025-04-11:
Probleme legate de PCB
-
**Via Stitching**
- Conform "Observatii si recomandari" din pagina de ocw a proiectului, trebuie aplicat Vias Stitching in jurul modulului ESP32
- `Fix`: https://www.autodesk.com/products/fusion-360/blog/understanding-the-power-of-via-stitching-in-pcb-design/

**GND plane**
- `Desc`: Chiar daca ai ground plane pe fata si pe spatele placii, ai fire de GND. Scopul ground plane-ului este pentru a le elimina.
- `Fix`: Ar trebui sa fie suficient sa scoti firele de ground si sa dai refill polygon pours.

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

- `Desc`: Cum a fost anuntat pe teams, trebuie eliminate zonele in care GND plane-ul este lipsa, fie pe top, fie pe bottom. In cazul tau, este o portiune in care nu exista nici GND plane pe top, nici pe bottom.
- `Fix`: Trebuie aplicate Vias-uri in aceste zone.

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

**Dimensiunea Placii**
- `Desc`: Pentru a incapea in carcasa, grosimea placii trebuie modificata de la 1.6mm la 1mm.
- `Fix`: https://forums.autodesk.com/t5/fusion-electronics/how-to-change-thickness-of-pcb-in-electronics-design/td-p/9367147

**Test Pads**
- `Desc`: Tot in "Observatii si Recomandari" este specificat ca fiecare test pad trebuie marcate cu semnalele pe car ele poarta.
- `Fix`: Schimba label-urile la Test Pad-uri astfel incat sa contina si semnalul, sau adauga un nou label.

**Plasarea componentelor**
- `Desc`: Plasarea componentelor pe PCB este usor haotica. Test Pad-urile mai ales, ar trebui sa fie mai grupate intre ele.
- `Fix`: Incearca sa aliniezi componentele si sa fie mai apropiate, acolo unde se poate.

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

**Erori DRC**
- `Desc`: Erori de overlap, generate de faptul ca sunt fire care se suprapun.
- `Fix`: Elimina firele care sunt in plus.

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

MBuzbuchi, 2025-04-16:
Am adaugat majoritatea modificarilor semnalate, multumesc mult de sprijin

Closed 2025-04-16.

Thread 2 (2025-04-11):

3D Models Issues

CosminCroitoriu, 2025-04-11:
3D PCB Model
-
**PFMF.050.1 dimension**
- `Desc`: Componenta PFMF.050.1 ar trebui marita, deoarece nu atinge cum ar trebui pinii.

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

**MCP73831 model 3d lipsa**
- `Desc`: Componentei MCP73831 ii lipseste modelul 3D.
- `Fix`: Adauga un model 3D de pe internet, precum acesta: https://app.ultralibrarian.com/details/E2CBFCCF-C6B2-11E9-AB3A-0A3560A4CCCC/Microchip/MCP73831-2ATI-MC

**Bobina 744043680 missplacement**
- `Desc`: Bobina este pusa invers pe PCB, pinii fiind in sus.

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

**Modelul final al produsului**
- `Desc`: Rezultatul final ar trebui sa fie cu PCB-ul, bateria si ecranul, impreuna, in interiorul carcasei. Plasarea lor te va ajuta sa vezi daca ai componente care sunt missplaced.

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

**Model 3D baterie**
- `Desc`: Modelul 3D al bateriei este facut bine, singurul lucru de adaugat ar fi sa marchezi bornele "+" si "-".
- `Fix`: Faci "+" si "-" din create sketch, iar apoi dai extrude cu o valoare negativa. Asta va avea ca efecta sa para ca semnele sunt gravate in baterie.

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

**Model 3D U1**
- 'Desc': Aceeasi situatie ca la bobina, componenta este pusa invers.
- 'Fix': Daca nu merge doar cu intoarcerea componentei, incearca sa o pui pe alta, precum: https://componentsearchengine.com/part-view/W25Q512JVEJQ/Winbond

MBuzbuchi, 2025-04-16:
Done thx

Closed 2025-04-16.

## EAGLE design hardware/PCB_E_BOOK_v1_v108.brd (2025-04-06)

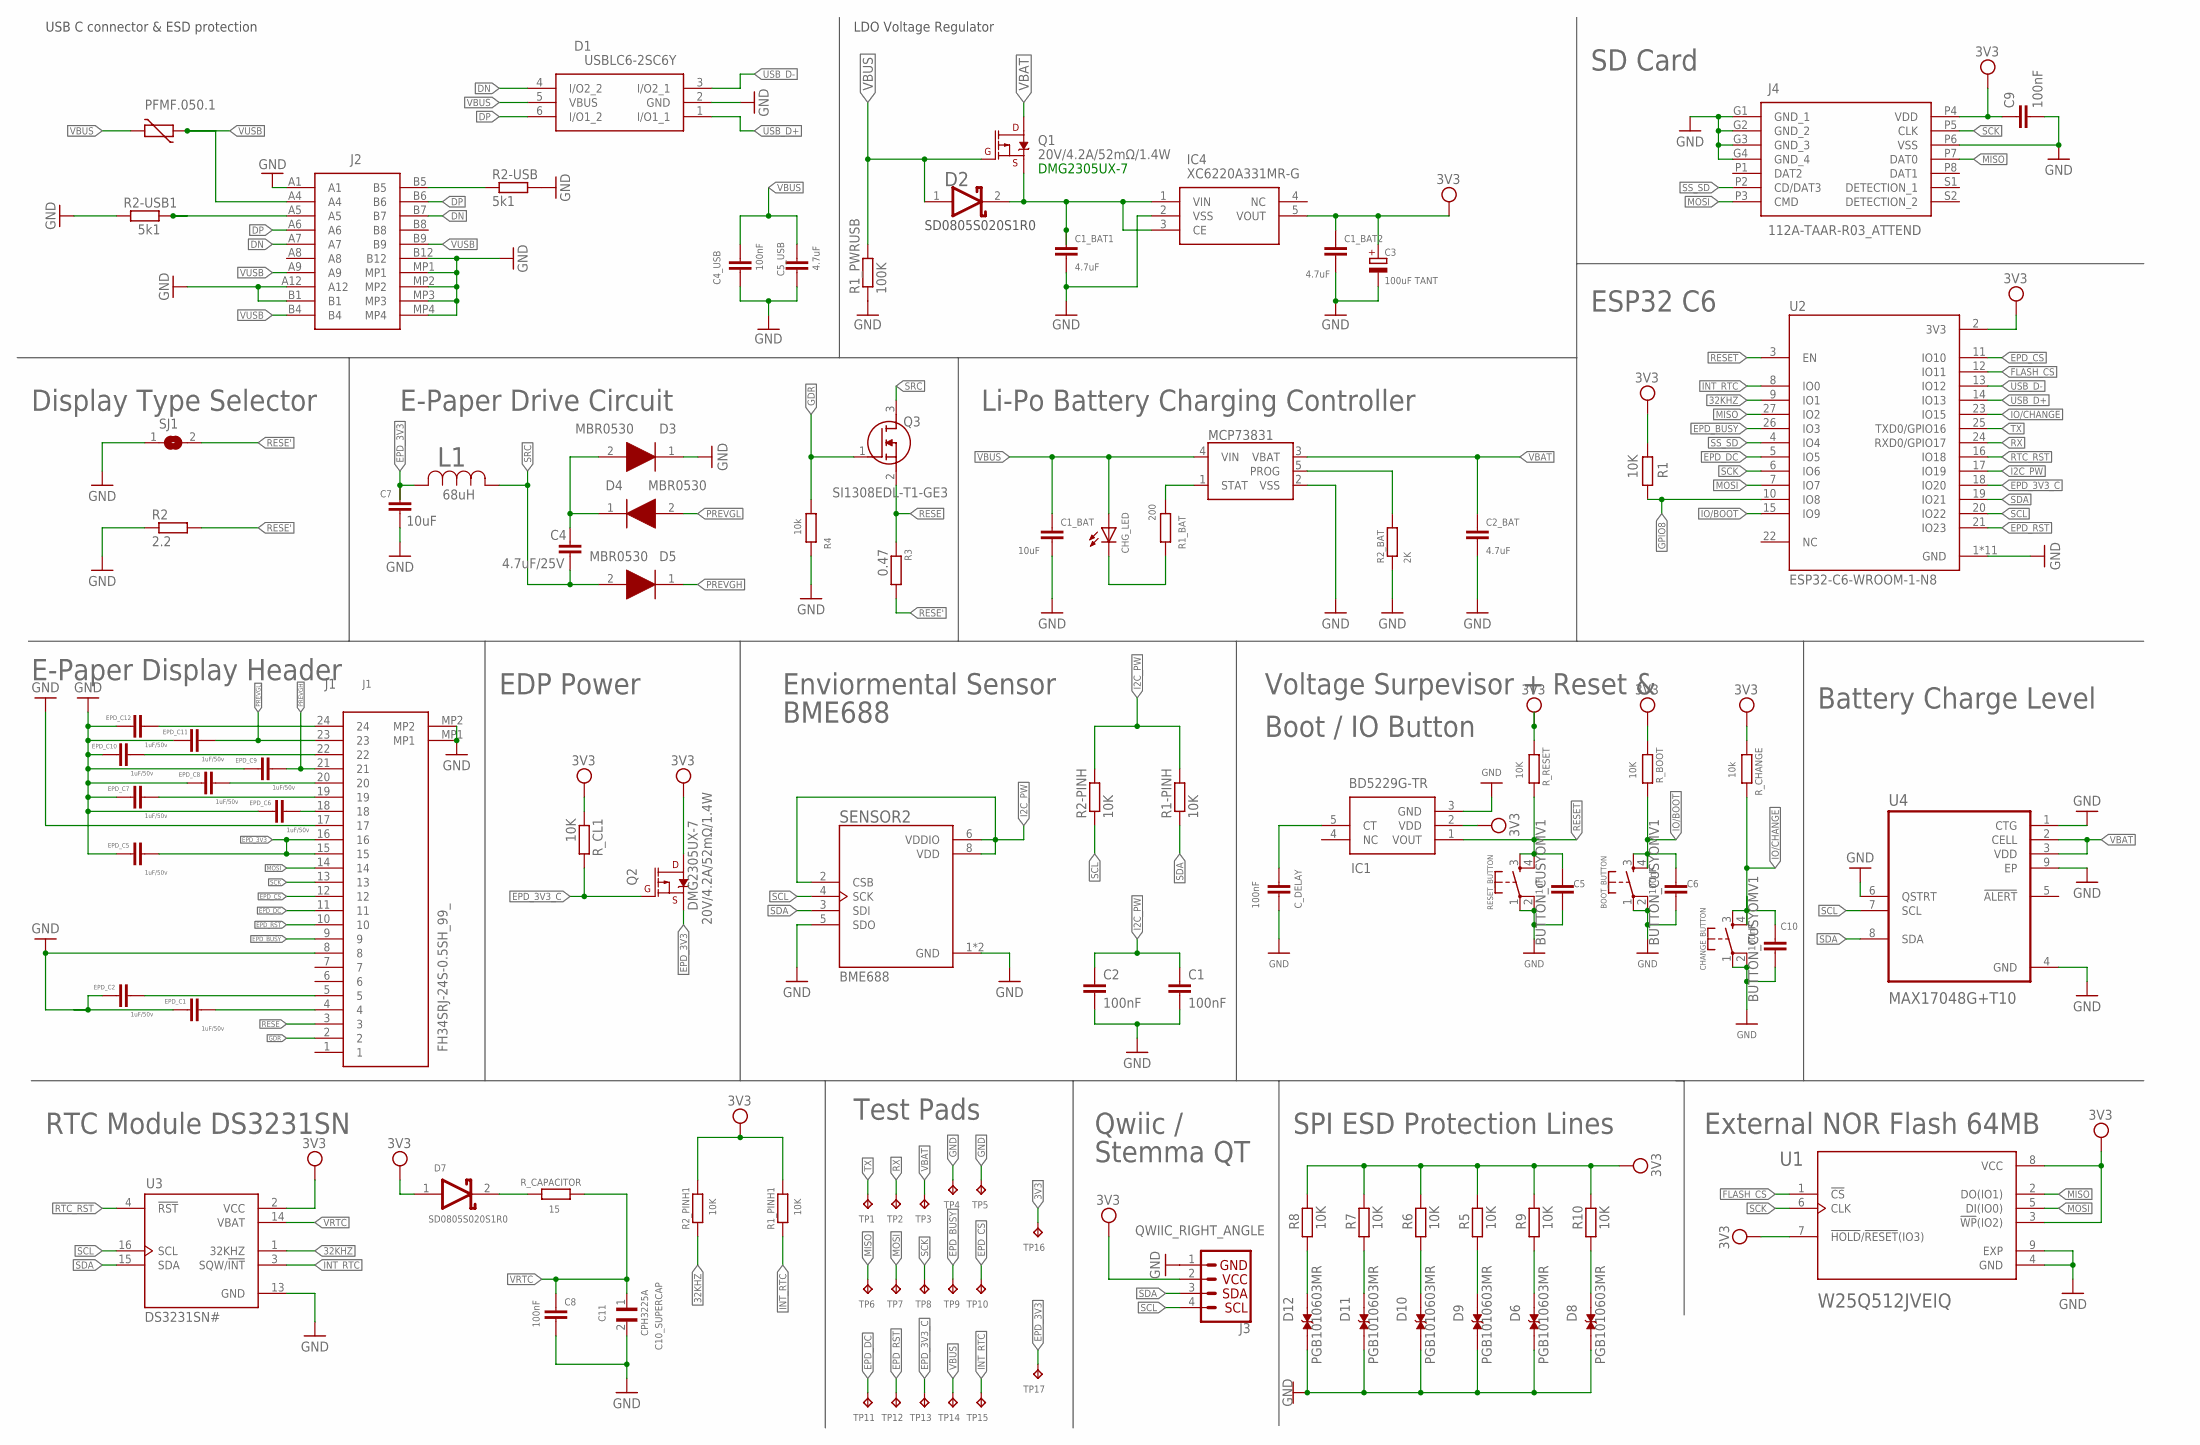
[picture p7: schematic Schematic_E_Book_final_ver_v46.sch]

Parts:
BOOT_BUTTON: BUTTON_CUSYOMV1; MYBUTTON
C1, C2, C4_USB, C6, C8, C9, C10: 100nF; EAGLE-LTSPICE_C0402
C1_BAT, C7: 10uF; EAGLE-LTSPICE_C0402
C1_BAT1, C1_BAT2, C2_BAT, C5_USB: 4.7uF; EAGLE-LTSPICE_C0402
C3: 100uF TANT; RCL_CT3528
C4: 4.7uF/25V; EAGLE-LTSPICE_C0402
C5: 1uF; EAGLE-LTSPICE_C0402
C11: CPH3225A; CAPCP3225X100N
CHANGE_BUTTON: BUTTON_CUSYOMV1; MYBUTTON
CHG_LED: ADAFRUIT_LEDCHIP-LED0603; ADAFRUIT_CHIP-LED0603
C_DELAY: 100nF; EAGLE-LTSPICE_C0402
D1: USBLC6-2SC6Y; SOT95P280X145-6N
D2: SD0805S020S1R0; ESP32_WROVER_AVX---SD0805S020S1R0_AVX_SD0805S020S1R0_0
D3, D4, D5: MBR0530; SOD3716X135N
D6, D8, D9, D10, D11, D12: PGB1010603MR; DIOC1608X36N
D7: ESP32_WROVER_AVX---SD0805S020S1R0_AVX_SD0805S020S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; ESP32_WROVER_AVX---SD0805S020S1R0_AVX_SD0805S020S1R0_0
EPD_C1, EPD_C2, EPD_C5, EPD_C6, EPD_C7, EPD_C8, EPD_C9, EPD_C10, EPD_C11, EPD_C12: 1uF/50v; EAGLE-LTSPICE_C0402
IC1: BD5229G-TR; SOT95P280X125-5N
IC4: XC6220A331MR-G; SOT95P280X120-5N
J1: FH34SRJ-24S-0.5SH_99_; FH34SRJ24S05SH99
J2: SAMACSYS_PARTS_USB4110-GF-A; SAMACSYS_PARTS_USB4110GFA
J3: QWIIC_RIGHT_ANGLE; JST04_1MM_RA
J4: 112A-TAAR-R03_ATTEND; 112ATAARR03ATTEND
L1: 68uH; IND_4828-WE-TPC_WRE
MCP73831: ESP32_WROVER_SPARKFUN-IC-POWER_MCP73831; ESP32_WROVER_SPARKFUN-IC-POWER_SOT23-5
PFMF.050.1: ESP32C6_VARISTORCN1812; ESP32C6_VARISTOR_CT/CN1812
Q1, Q2: 20V/4.2A/52mΩ/1.4W; ESP32_WROVER_SPARKFUN-DISCRETESEMI_SOT23-3
Q3: SI1308EDL-T1-GE3; SOT65P210X110-3N
R1, R1-PINH, R1_PINH1, R2-PINH, R2_PINH1, R5, R6, R7, R8, R9, R10: 10K; ESP32_WROVER_EAGLE-LTSPICE_R0402
R1_BAT: 200; ESP32_WROVER_EAGLE-LTSPICE_R0402
R1_PWRUSB: 100K; ESP32_WROVER_EAGLE-LTSPICE_R0402
R2: 2.2; ESP32_WROVER_EAGLE-LTSPICE_R0402
R2-USB, R2-USB1: 5k1; ESP32_WROVER_EAGLE-LTSPICE_R0402
R2_BAT: 2K; ESP32_WROVER_EAGLE-LTSPICE_R0402
R3: 0.47; ESP32_WROVER_EAGLE-LTSPICE_R0402
R4: 10k; ESP32_WROVER_EAGLE-LTSPICE_R0402
RESET_BUTTON: BUTTON_CUSYOMV1; MYBUTTON
R_BOOT: 10K; ESP32_WROVER_EAGLE-LTSPICE_R0402
R_CAPACITOR: 15; ESP32_WROVER_EAGLE-LTSPICE_R0402
R_CHANGE: 10k; ESP32_WROVER_EAGLE-LTSPICE_R0402
R_CL1: 10K; ESP32_WROVER_EAGLE-LTSPICE_R0402
R_RESET: 10K; ESP32_WROVER_EAGLE-LTSPICE_R0402
SENSOR2: ESP32_WROVER_BME680_BME680; ESP32_WROVER_BME680_PSON80P300X300X100-8N
SJ1: SJ
TP1, TP2, TP3, TP4, TP5, TP6, TP7, TP8, TP9, TP10, TP11, TP12, TP13, TP14, TP15, TP16, TP17: TPTP20R; TP20R
U1: W25Q512JVEIQ; SON127P600X800X80-9N
U2: ESP32-C6-WROOM-1-N8; XCVR_ESP32-C6-WROOM-1-N8
U3: DS3231SN#; SOIC127P1032X265-16N
U4: MAX17048G+T10; SON50P200X200X80-9N

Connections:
3V3: C1_BAT2.1, C3.+, C9.1, D7.1 (ANODE), IC1.2 (VDD), IC4.5 (VOUT), J3.2, J4.P4 (VDD), Q2.3 (D), R1.2, R1_PINH1.2, R2_PINH1.2, R5.2, R6.2, R7.2, R8.2, R9.2, R10.2, R_BOOT.1, R_CHANGE.1, R_CL1.1, R_RESET.1, TP16.TP, U1.3 (!WP!(IO2)), U1.7 (!HOLD!/!RESET!(IO3)), U1.8 (VCC), U2.2 (3V3), U3.2 (VCC)
32KHZ: R2_PINH1.1, U2.9 (IO1), U3.1 (32KHZ)
DN: D1.4 (I/O2_2), J2.A7, J2.B7
DP: D1.6 (I/O1_2), J2.A6, J2.B6
EPD_3V3: C7.1, EPD_C5.1, J1.15, J1.16, L1.2, Q2.2 (S), TP17.TP
EPD_3V3_C: Q2.1 (G), R_CL1.2, TP13.TP, U2.18 (IO20)
EPD_BUSY: J1.9, TP9.TP, U2.26 (IO3)
EPD_CS: J1.12, TP10.TP, U2.11 (IO10)
EPD_DC: J1.11, TP11.TP, U2.5 (IO5)
EPD_RST: J1.10, TP12.TP, U2.21 (IO23)
FLASH_CS: U1.1 (!CS), U2.12 (IO11)
GDR: J1.2, Q3.1 (G), R4.2
GND: BOOT_BUTTON.1, BOOT_BUTTON.2, C1.2, C1_BAT.2, C1_BAT1.2, C1_BAT2.2, C2.2, C2_BAT.2, C3.-, C4_USB.2, C5.2, C5_USB.2, C6.2, C7.2, C8.2, C9.2, C10.2, C11.2, CHANGE_BUTTON.1, CHANGE_BUTTON.2, C_DELAY.2, D1.2 (GND), D3.1 (K), D6.1, D8.1, D9.1, D10.1, D11.1, D12.1, EPD_C1.2, EPD_C2.2, EPD_C5.2, EPD_C6.2, EPD_C7.2, EPD_C8.2, EPD_C9.2, EPD_C10.2, EPD_C11.2, EPD_C12.2, IC1.3 (GND), IC4.2 (VSS), J1.8, J1.17, J1.MP1, J1.MP2, J2.A1, J2.A12, J2.B1, J2.B12, J2.MP1, J2.MP2, J2.MP3, J2.MP4, J3.1, J4.G1 (GND_1), J4.G2 (GND_2), J4.G3 (GND_3), J4.G4 (GND_4), J4.P6 (VSS), MCP73831.2 (VSS), R1_PWRUSB.1, R2.1, R2-USB.2, R2-USB1.1, R2_BAT.1, R4.1, RESET_BUTTON.1, RESET_BUTTON.2, SENSOR2.1 (GND), SENSOR2.5 (SDO), SENSOR2.7 (GND), SJ1.1, TP4.TP, TP5.TP, U1.4 (GND), U1.9 (EXP), U2.1 (GND), U2.28 (GND), U2.29_1 (GND), U2.29_2 (GND), U2.29_3 (GND), U2.29_4 (GND), U2.29_5 (GND), U2.29_6 (GND), U2.29_7 (GND), U2.29_8 (GND), U2.29_9 (GND), U3.13 (GND), U4.1 (CTG), U4.4 (GND), U4.6 (QSTRT), U4.9 (EP)
GPIO8: R1.1, U2.10 (IO8)
I2C_PW: C1.1, C2.1, R1-PINH.2, R2-PINH.2, SENSOR2.2 (CSB), SENSOR2.6 (VDDIO), SENSOR2.8 (VDD), U2.17 (IO19)
INT_RTC: R1_PINH1.1, TP15.TP, U2.8 (IO0), U3.3 (SQW/!INT)
IO/BOOT: BOOT_BUTTON.3, BOOT_BUTTON.4, C6.1, R_BOOT.2, U2.15 (IO9)
IO/CHANGE: C10.1, CHANGE_BUTTON.3, CHANGE_BUTTON.4, R_CHANGE.2, U2.23 (IO15)
MISO: J4.P7 (DAT0), TP6.TP, U1.2 (DO(IO1)), U2.27 (IO2)
MOSI: J1.14, J4.P3 (CMD), TP7.TP, U1.5 (DI(IO0)), U2.7 (IO7)
unnamed: J2.A5, R2-USB1.2
unnamed: C1_BAT1.1, D2.2 (CATHODE), IC4.1 (VIN), IC4.3 (CE), Q1.2 (S)
unnamed: MCP73831.1 (STAT), R1_BAT.2
unnamed: MCP73831.5 (PROG), R2_BAT.2
unnamed: J2.B5, R2-USB.1
unnamed: CHG_LED.C, R1_BAT.1
unnamed: C4.1, D3.2 (A), D4.1 (K)
unnamed: D12.2, R8.1
unnamed: D11.2, R7.1
unnamed: D10.2, R6.1
unnamed: D9.2, R5.1
unnamed: D6.2, R9.1
unnamed: D8.2, R10.1
unnamed: C_DELAY.1, IC1.5 (CT)
unnamed: D7.2 (CATHODE), R_CAPACITOR.1
unnamed: EPD_C2.1, J1.5
unnamed: EPD_C1.1, J1.4
PREVGH: D5.1 (K), EPD_C9.1, J1.21
PREVGL: D4.2 (A), EPD_C11.1, J1.23
RESE: J1.3, Q3.2 (S), R3.1
RESE': R2.2, R3.2, SJ1.2
RESET: C5.1, IC1.1 (VOUT), RESET_BUTTON.3, RESET_BUTTON.4, R_RESET.2, U2.3 (EN)
RTC_RST: U2.16 (IO18), U3.4 (!RST)
RX: TP2.TP, U2.24 (RXD0/GPIO17)
SCK: J1.13, J4.P5 (CLK), TP8.TP, U1.6 (CLK), U2.6 (IO6)
SCL: J3.4, R2-PINH.1, SENSOR2.4 (SCK), U2.20 (IO22), U3.16 (SCL), U4.7 (SCL)
SDA: J3.3, R1-PINH.1, SENSOR2.3 (SDI), U2.19 (IO21), U3.15 (SDA), U4.8 (SDA)
SRC: C4.2, D5.2 (A), L1.1, Q3.3 (D)
SS_SD: J4.P2 (CD/DAT3), U2.4 (IO4)
TX: TP1.TP, U2.25 (TXD0/GPIO16)
USB_D+: D1.1 (I/O1_1), U2.14 (IO13)
USB_D-: D1.3 (I/O2_1), U2.13 (IO12)
VBAT: C2_BAT.1, MCP73831.3 (VBAT), Q1.3 (D), TP3.TP, U4.2 (CELL), U4.3 (VDD)
VBUS: C1_BAT.1, C4_USB.1, C5_USB.1, CHG_LED.A, D1.5 (VBUS), D2.1 (ANODE), MCP73831.4 (VIN), PFMF.050.1.2, Q1.1 (G), R1_PWRUSB.2, TP14.TP
VRTC: C8.1, C11.1, R_CAPACITOR.2, U3.14 (VBAT)
VRTC1: EPD_C12.1, J1.24
VRTC4: EPD_C8.1, J1.20
VRTC5: EPD_C7.1, J1.19
VRTC6: EPD_C6.1, J1.18
VRTC7: EPD_C10.1, J1.22
VUSB: J2.A4, J2.A9, J2.B4, J2.B9, PFMF.050.1.1

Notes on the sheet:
USB C connector & ESD protection
SD0805S020S1R0
DMG2305UX-7
LDO Voltage Regulator
SD Card
ESP32 C6
Li-Po Battery Charging Controller
E-Paper Drive Circuit
Display Type Selector
EDP Power
Battery Charge Level
External NOR Flash 64MB
SPI ESD Protection Lines
Qwiic /
Stemma QT
Test Pads
BME688
Enviormental Sensor
BME688
Voltage Surpevisor + Reset &
Boot / IO Button
RTC Module DS3231SN
C10_SUPERCAP
E-Paper Display Header
68uH

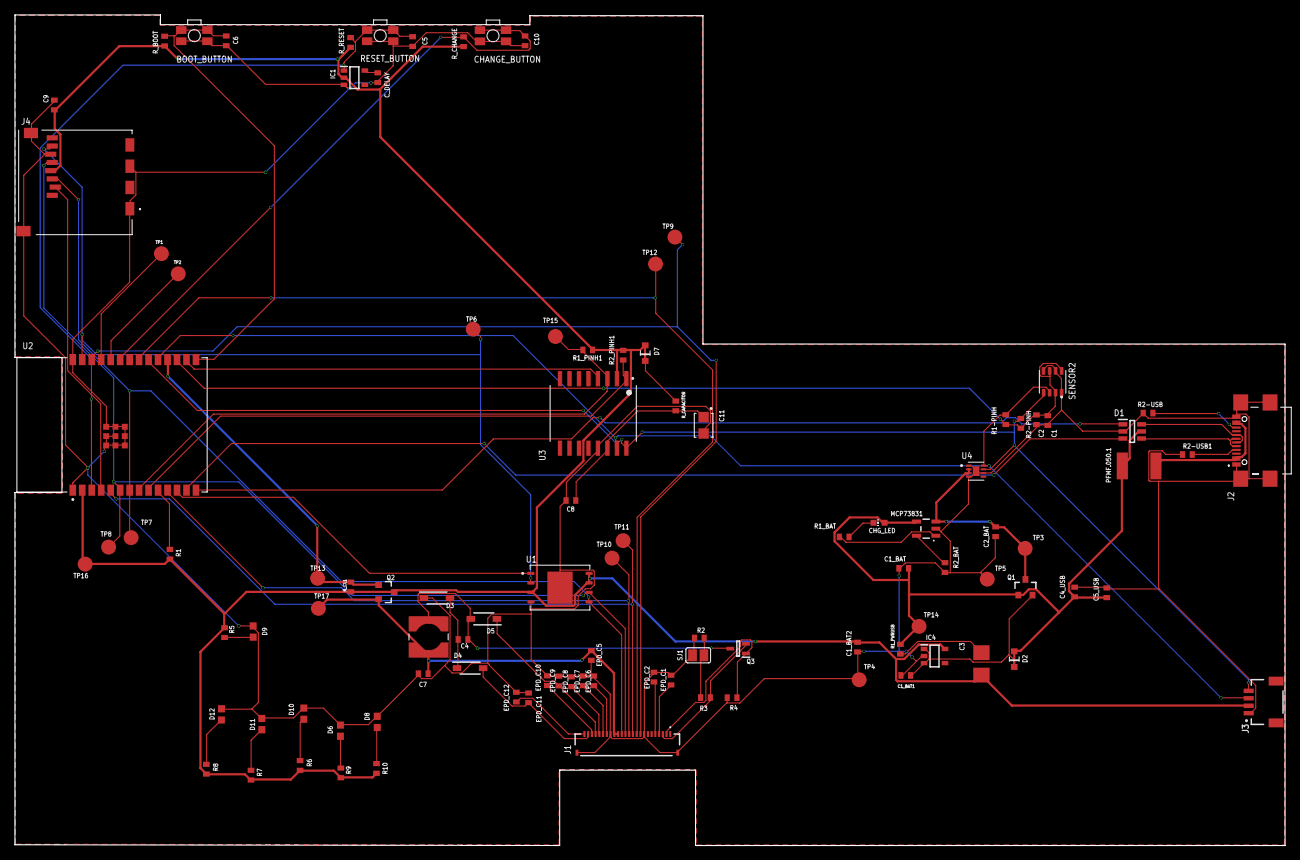
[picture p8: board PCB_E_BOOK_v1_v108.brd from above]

Board: 2 copper layers, 170.2 x 111.3 mm, 103 parts (0 on the bottom side), 61 nets.
